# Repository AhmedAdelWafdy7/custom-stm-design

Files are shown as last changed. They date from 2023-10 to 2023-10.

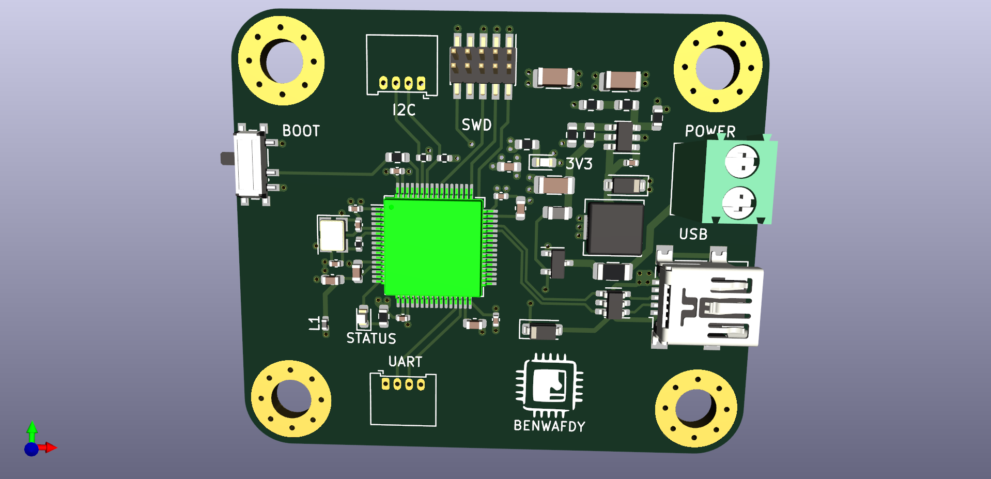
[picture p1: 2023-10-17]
custom_stm_design_Front.png

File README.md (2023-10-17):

# Custom STM Design

This is a README file for the custom-stm-design PCB board, a versatile and powerful board that features the STM32F405 MCU. This board can handle a wide range of applications, thanks to its rich set of peripherals and interfaces. 

The board supports power supply from +12V, using a buck converter to regulate the voltage for the MCU and other components. It also supports USB power and data, allowing you to connect the board to your computer or other devices. You can use the USB interface to program, debug, or communicate with the board.

The board also provides UART and I2C interfaces, which are useful for serial communication with sensors, actuators, or other boards. You can use these interfaces to expand the functionality of your board or integrate it with other systems.

Finally, the board supports SWD debugging, which is a low-pin-count interface that allows you to access the core features of the MCU. You can use SWD debugging to monitor, control, or modify the behavior of your board in real time.

The custom-stm-design PCB board is a great choice for anyone who wants to explore the capabilities of the STM32F405 MCU or create their own projects using this powerful and flexible platform. You can find more information about the board specifications, schematics, and firmware in the following sections.

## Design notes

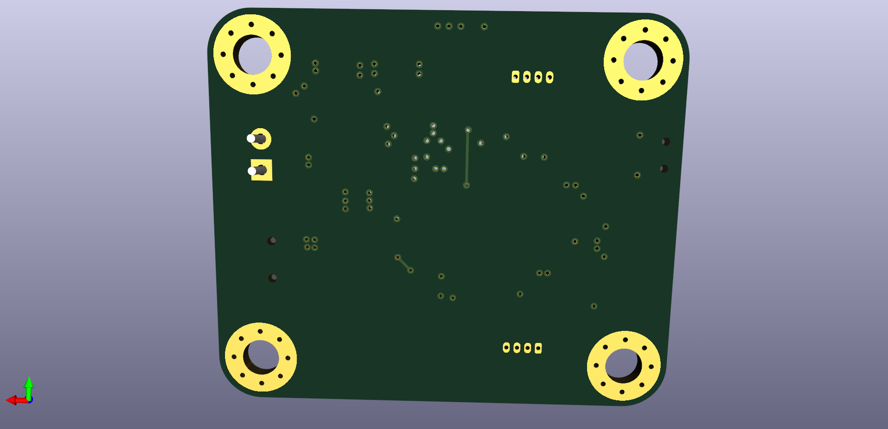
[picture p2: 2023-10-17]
custom_stm_design_back.png

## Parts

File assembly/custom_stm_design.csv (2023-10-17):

Source: | D:\PCB DESIGN\custom_stm_design\custom_stm_design.kicad_sch
Date: | 10/17/2023 2:44:29 AM
Tool: | Eeschema 7.0.7
Generator: | C:\Program Files\KiCad\7.0\bin\scripting\plugins/bom_csv_grouped_by_value_with_fp.py
Component Count: | 50
Ref | Qnty | Value | Cmp name | Footprint | Description | Vendor | DNP
C1, C2 | 2 | 10P | C_Small | Capacitor_SMD:C_0402_1005Metric | Unpolarized capacitor, small symbol
C3 | 1 | 4u7 | C_Small | Capacitor_SMD:C_0603_1608Metric | Unpolarized capacitor, small symbol
C4, C5, C6, C7, C8 | 5 | 100n | C_Small | Capacitor_SMD:C_0402_1005Metric | Unpolarized capacitor, small symbol
C9, C10 | 2 | 2u2 | C_Small | Capacitor_SMD:C_0603_1608Metric | Unpolarized capacitor, small symbol
C11 | 1 | 1u | C_Small | Capacitor_SMD:C_0603_1608Metric | Unpolarized capacitor, small symbol
C12 | 1 | 10n | C_Small | Capacitor_SMD:C_0603_1608Metric | Unpolarized capacitor, small symbol
C13, C14, C15 | 3 | 10u | C_Small | Capacitor_SMD:C_1206_3216Metric | Unpolarized capacitor, small symbol
C16 | 1 | 10n | C_Small | Capacitor_SMD:C_0402_1005Metric | Unpolarized capacitor, small symbol
D1 | 1 | LED | LED | LED_SMD:LED_0603_1608Metric | Light emitting diode
D2, D3 | 2 | B5819W | D_Schottky_Small | Diode_SMD:D_SOD-123 | Schottky diode, small symbol
D4 | 1 | RED | LED | LED_SMD:LED_0603_1608Metric | Light emitting diode
F1 | 1 | 250mA | Polyfuse_Small | Fuse:Fuse_1206_3216Metric | Resettable fuse, polymeric positive temperature coefficient, small symbol
FB1 | 1 | 600 @ 600MHZ | FerriteBead_Small | Inductor_SMD:L_0805_2012Metric | Ferrite bead, small symbol
H1, H2, H3, H4 | 4 | MountingHole_Pad | MountingHole_Pad | MountingHole:MountingHole_4.3mm_M4_Pad_Via | Mounting Hole with connection
J1 | 1 | INPUT_POWER | Screw_Terminal_01x02 | TerminalBlock_Phoenix:TerminalBlock_Phoenix_PT-1,5-2-3.5-H_1x02_P3.50mm_Horizontal | Generic screw terminal, single row, 01x02, script generated (kicad-library-utils/schlib/autogen/connector/)
J2 | 1 | SWD | Conn_02x05_Odd_Even | Connector_PinHeader_1.27mm:PinHeader_2x05_P1.27mm_Vertical_SMD | Generic connector, double row, 02x05, odd/even pin numbering scheme (row 1 odd numbers, row 2 even numbers), script generated (kicad-library-utils/schlib/autogen/connector/)
J3 | 1 | I2C | Conn_01x04 | Connector_Molex:Molex_PicoBlade_53048-0410_1x04_P1.25mm_Horizontal | Generic connector, single row, 01x04, script generated (kicad-library-utils/schlib/autogen/connector/)
J4 | 1 | USB_B_Micro | USB_B_Micro | Connector_USB:USB_Mini-B_Lumberg_2486_01_Horizontal | USB Micro Type B connector
J5 | 1 | UART | Conn_01x04 | Connector_Molex:Molex_PicoBlade_53048-0410_1x04_P1.25mm_Horizontal | Generic connector, single row, 01x04, script generated (kicad-library-utils/schlib/autogen/connector/)
L1 | 1 | 39n | L_Small | Inductor_SMD:L_0402_1005Metric | Inductor, small symbol
L2 | 1 | 10u | L_Small | Inductor_SMD:L_Sunlord_MWSA0518S | Inductor, small symbol
Q1 | 1 | AO3401A | AO3401A | Package_TO_SOT_SMD:SOT-23 | -4.0A Id, -30V Vds, P-Channel MOSFET, SOT-23
R1 | 1 | 47 | R_Small | Resistor_SMD:R_0402_1005Metric | Resistor, small symbol
R2 | 1 | 1K5 | R_Small | Resistor_SMD:R_0603_1608Metric | Resistor, small symbol
R3 | 1 | 10K | R_Small | Resistor_SMD:R_0603_1608Metric | Resistor, small symbol
R4, R5 | 2 | 2K2 | R_Small | Resistor_SMD:R_0402_1005Metric | Resistor, small symbol
R6 | 1 | 47K | R_Small | Resistor_SMD:R_0603_1608Metric | Resistor, small symbol
R7 | 1 | 15K | R_Small | Resistor_SMD:R_0603_1608Metric | Resistor, small symbol
R8 | 1 | 270 | R_Small | Resistor_SMD:R_0603_1608Metric | Resistor, small symbol
R9 | 1 | 1K | R_Small | Resistor_SMD:R_0603_1608Metric | Resistor, small symbol
R10 | 1 | 100K | R_Small | Resistor_SMD:R_0603_1608Metric | Resistor, small symbol
R11 | 1 | 68K | R_Small | Resistor_SMD:R_0603_1608Metric | Resistor, small symbol
SW1 | 1 | SW_SPDT | SW_SPDT | Button_Switch_SMD:SW_SPDT_PCM12 | Switch, single pole double throw
U1 | 1 | STM32F405RGTx | STM32F405RGTx | Package_QFP:LQFP-64_10x10mm_P0.5mm | STMicroelectronics Arm Cortex-M4 MCU, 1024KB flash, 192KB RAM, 168 MHz, 1.8-3.6V, 51 GPIO, LQFP64
U2 | 1 | ~ | MP2359DJ-LF-Z | Package_TO_SOT_SMD:SOT-23-6
U3 | 1 | USBLC6-2SC6 | USBLC6-2SC6 | Package_TO_SOT_SMD:SOT-23-6 | Very low capacitance ESD protection diode, 2 data-line, SOT-23-6
Y1 | 1 | 16MHz | Crystal_GND24 | Crystal:Crystal_SMD_3225-4Pin_3.2x2.5mm | Four pin crystal, GND on pins 2 and 4

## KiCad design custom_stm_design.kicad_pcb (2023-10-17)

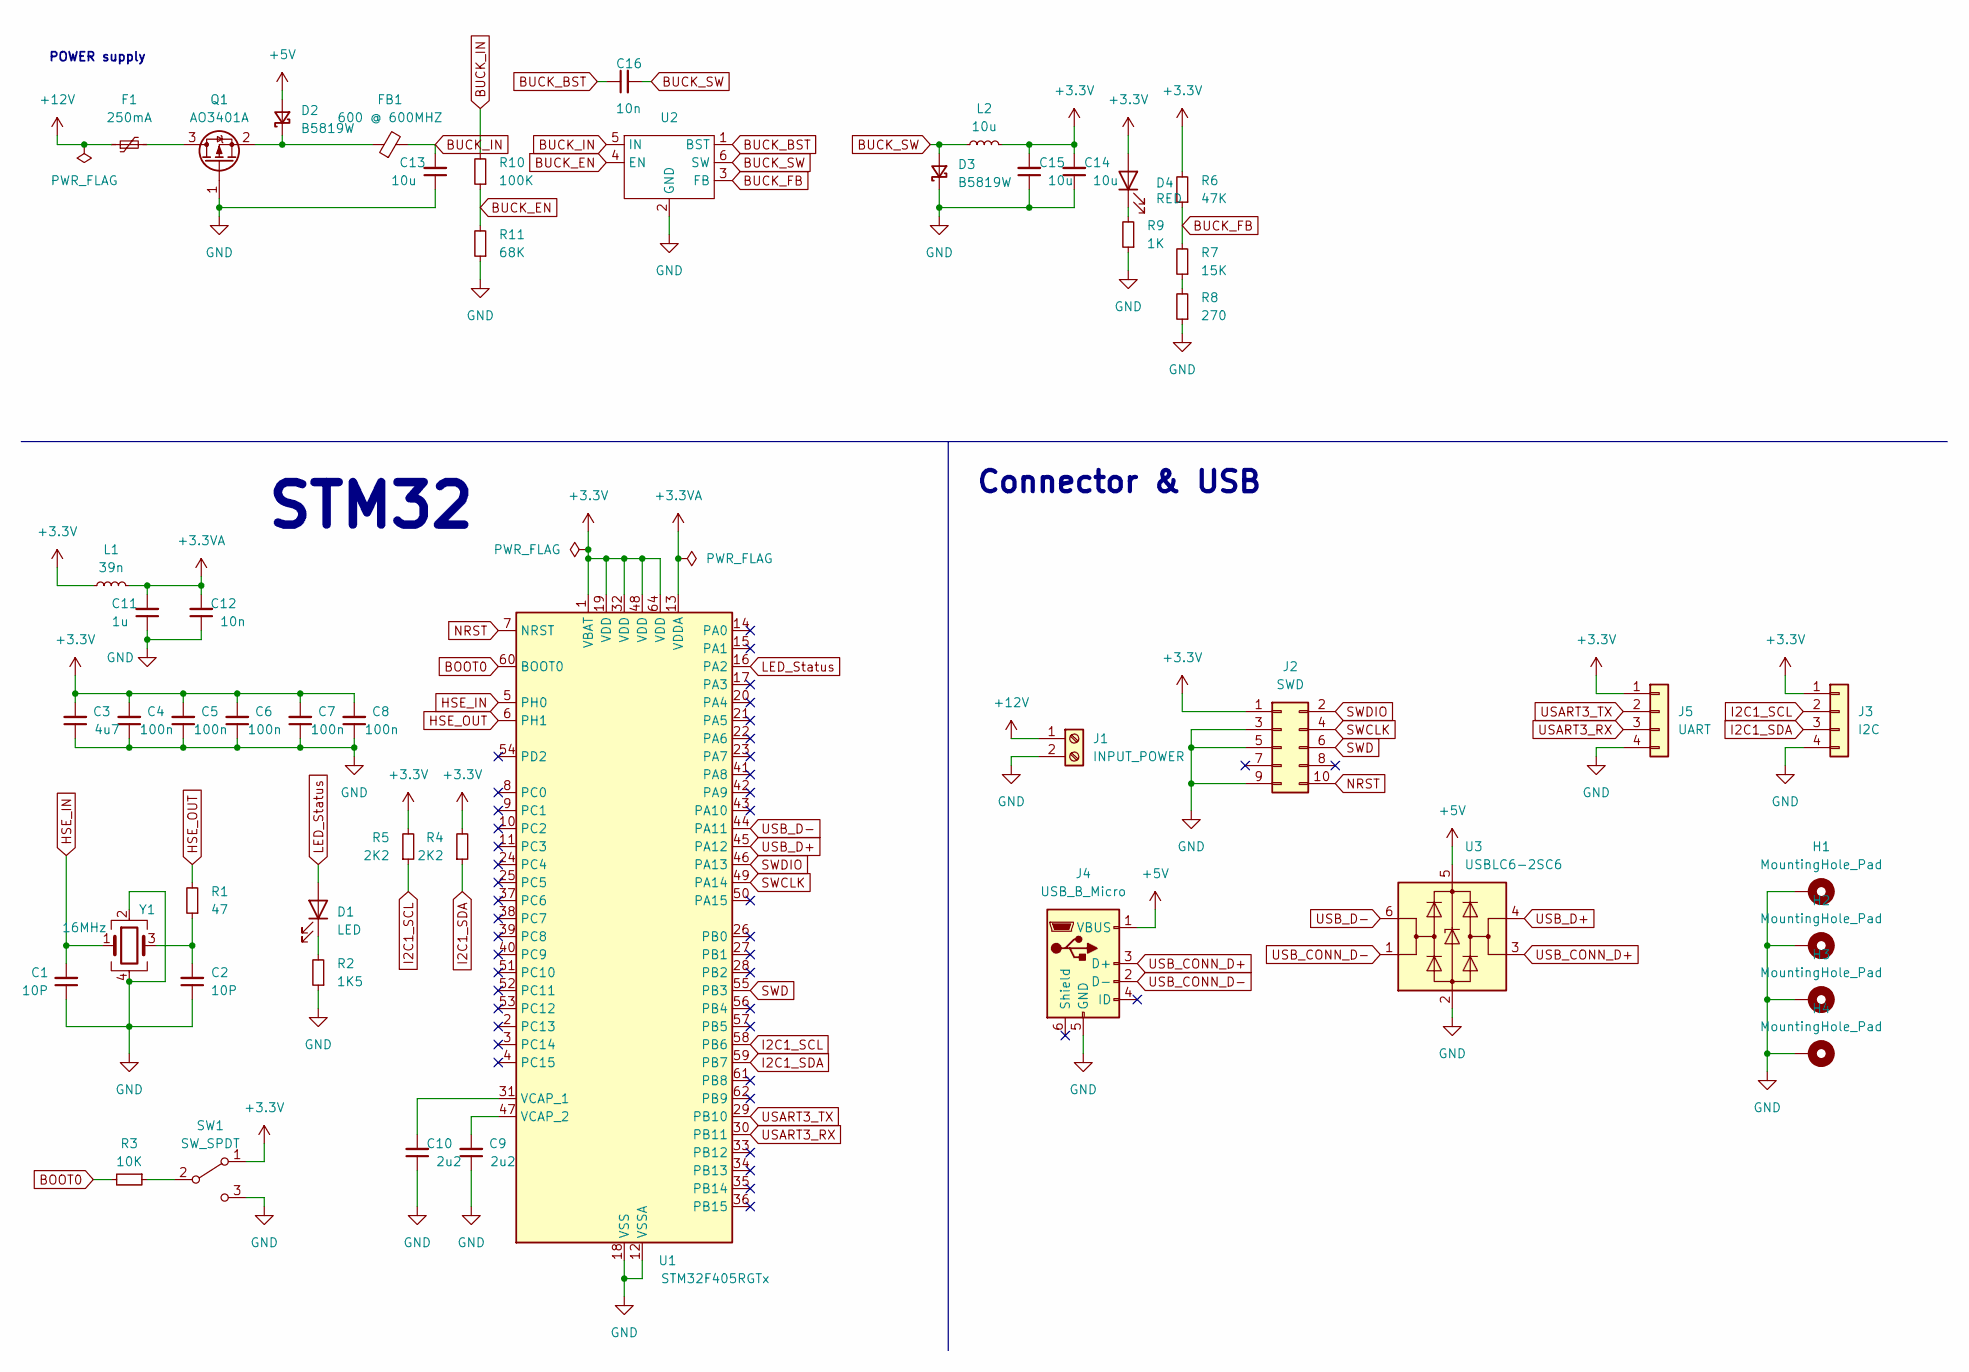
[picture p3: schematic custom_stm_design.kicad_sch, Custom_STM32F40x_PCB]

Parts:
C1, C2: 10P; C_0402_1005Metric
C3: 4u7; C_0603_1608Metric
C4, C5, C6, C7, C8: 100n; C_0402_1005Metric
C9, C10: 2u2; C_0603_1608Metric
C11: 1u; C_0603_1608Metric
C12: 10n; C_0603_1608Metric
C13, C14, C15: 10u; C_1206_3216Metric
C16: 10n; C_0402_1005Metric
D1: LED; LED_0603_1608Metric
D2, D3: B5819W; D_SOD-123
D4: RED; LED_0603_1608Metric
F1: 250mA; Fuse_1206_3216Metric
FB1: 600 @ 600MHZ; L_0805_2012Metric
H1, H2, H3, H4: MountingHole_Pad; MountingHole_4.3mm_M4_Pad_Via
J1: INPUT_POWER; TerminalBlock_Phoenix_PT-1,5-2-3.5-H_1x02_P3.50mm_Horizontal
J2: SWD; PinHeader_2x05_P1.27mm_Vertical_SMD
J3: I2C; Molex_PicoBlade_53048-0410_1x04_P1.25mm_Horizontal
J4: USB_B_Micro; USB_Mini-B_Lumberg_2486_01_Horizontal
J5: UART; Molex_PicoBlade_53048-0410_1x04_P1.25mm_Horizontal
L1: 39n; L_0402_1005Metric
L2: 10u; L_Sunlord_MWSA0518S
Q1: AO3401A; SOT-23
R1: 47; R_0402_1005Metric
R2: 1K5; R_0603_1608Metric
R3: 10K; R_0603_1608Metric
R4, R5: 2K2; R_0402_1005Metric
R6: 47K; R_0603_1608Metric
R7: 15K; R_0603_1608Metric
R8: 270; R_0603_1608Metric
R9: 1K; R_0603_1608Metric
R10: 100K; R_0603_1608Metric
R11: 68K; R_0603_1608Metric
SW1: SW_SPDT; SW_SPDT_PCM12
U1: STM32F405RGTx; LQFP-64_10x10mm_P0.5mm
U2: SOT-23-6
U3: USBLC6-2SC6; SOT-23-6
Y1: 16MHz; Crystal_SMD_3225-4Pin_3.2x2.5mm

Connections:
+3.3V: C3.2, C4.2, C5.2, C6.2, C7.2, C8.2, C14.2, C15.2, D4.2 (A), J2.1, J3.1, J5.1, L1.1, L2.2, R4.2, R5.2, R6.2, SW1.1 (A), U1.1 (VBAT), U1.19 (VDD), U1.32 (VDD), U1.48 (VDD), U1.64 (VDD)
+3.3VA: C11.2, C12.2, L1.2, U1.13 (VDDA)
+5V: D2.2 (A), J4.1 (VBUS), U3.5 (VBUS)
+12V: F1.1, J1.1
BOOT0: R3.2, U1.60 (BOOT0)
BUCK_BST: C16.1, U2.1 (BST)
BUCK_EN: R10.1, R11.2, U2.4 (EN)
BUCK_FB: R6.1, R7.2, U2.3 (FB)
BUCK_IN: C13.2, FB1.2, R10.2, U2.5 (IN)
BUCK_SW: C16.2, D3.2 (A), L2.1, U2.6 (SW)
GND: C1.1, C2.1, C3.1, C4.1, C5.1, C6.1, C7.1, C8.1, C9.1, C10.1, C11.1, C12.1, C13.1, C14.1, C15.1, D3.1 (K), H1.1, H2.1, H3.1, H4.1, J1.2, J2.3, J2.5, J2.9, J3.4, J4.5 (GND), J5.4, Q1.1 (G), R2.1, R8.1, R9.1, R11.1, SW1.3 (C), U1.12 (VSSA), U1.18 (VSS), U1.63 (VSS), U2.2 (GND), U3.2 (GND), Y1.2, Y1.4
HSE_IN: C1.2, U1.5 (PH0), Y1.1
HSE_OUT: R1.2, U1.6 (PH1)
I2C1_SCL: J3.2, R5.1, U1.58 (PB6)
I2C1_SDA: J3.3, R4.1, U1.59 (PB7)
LED_Status: D1.2 (A), U1.16 (PA2)
NRST: J2.10, U1.7 (NRST)
unnamed: C2.2, R1.1, Y1.3
unnamed: D1.1 (K), R2.2
unnamed: D2.1 (K), FB1.1, Q1.2 (S)
unnamed: D4.1 (K), R9.2
unnamed: F1.2, Q1.3 (D)
unnamed: R7.1, R8.2
unnamed: R3.1, SW1.2 (B)
unnamed: C10.2, U1.31 (VCAP_1)
unnamed: C9.2, U1.47 (VCAP_2)
SWCLK: J2.4, U1.49 (PA14)
SWD: J2.6, U1.55 (PB3)
SWDIO: J2.2, U1.46 (PA13)
USART3_RX: J5.3, U1.30 (PB11)
USART3_TX: J5.2, U1.29 (PB10)
USB_CONN_D+: J4.3 (D+), U3.3 (I/O2)
USB_CONN_D-: J4.2 (D-), U3.1 (I/O1)
USB_D+: U1.45 (PA12), U3.4 (I/O2)
USB_D-: U1.44 (PA11), U3.6 (I/O1)

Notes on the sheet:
POWER supply
Connector & USB
STM32

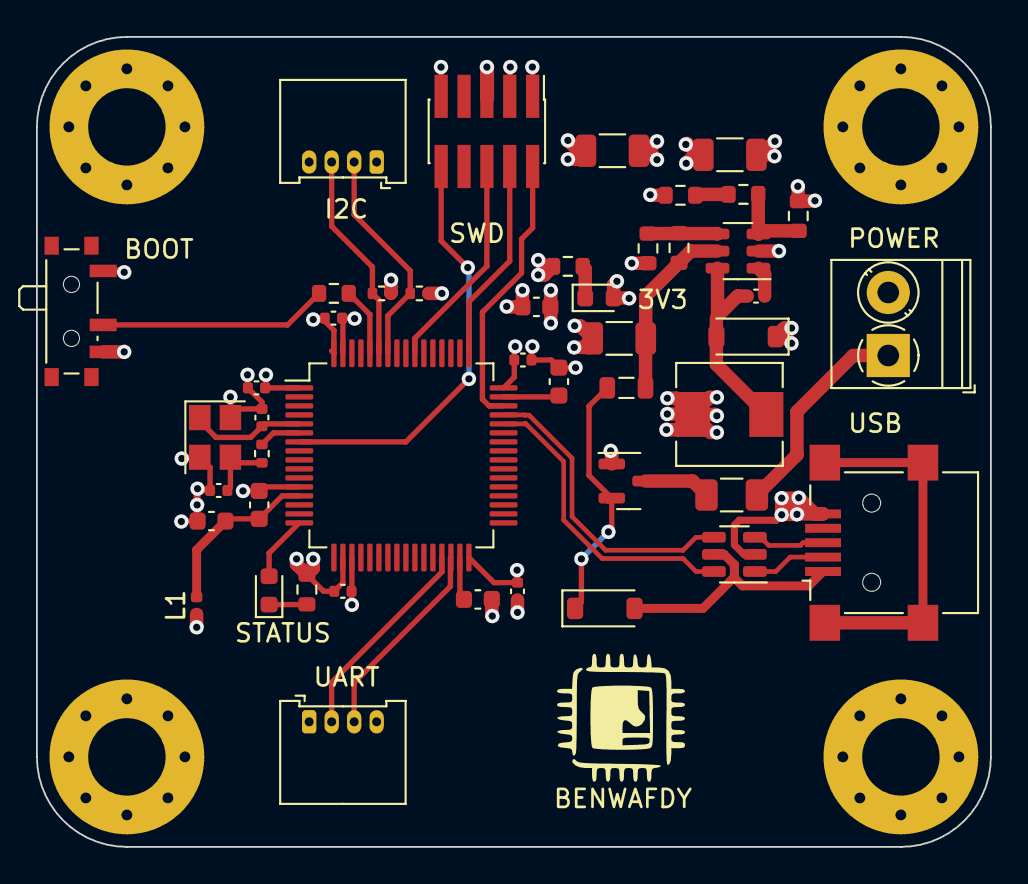
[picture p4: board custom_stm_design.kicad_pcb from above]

Board: 4 copper layers, 53.0 x 45.0 mm, 50 parts (0 on the bottom side), 35 nets.
